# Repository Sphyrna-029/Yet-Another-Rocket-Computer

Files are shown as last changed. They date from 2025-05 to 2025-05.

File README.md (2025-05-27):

# Yet-Another-Rocket-Computer
YARC (Yet Another Rocket Comptuer). Rocket flight computers are all the craze nowa-days. This is my attempt at one.

##### Features
 - 3-axis gyroscope and a 3-axis accelerometer (MPU6050)
 - GPS (LC86G with built in patch)
 - Telemetry (1 Watt Ebyte E22 Lora Module)
 - Total footprint is 35mm x 90mm
<br/>
<br/>
Firmware will track flight events (launch, apogee, landing), altitude, location, and attitude. In addition to aiding in post flight recovery. 
<br/>
<br/>
<br/>

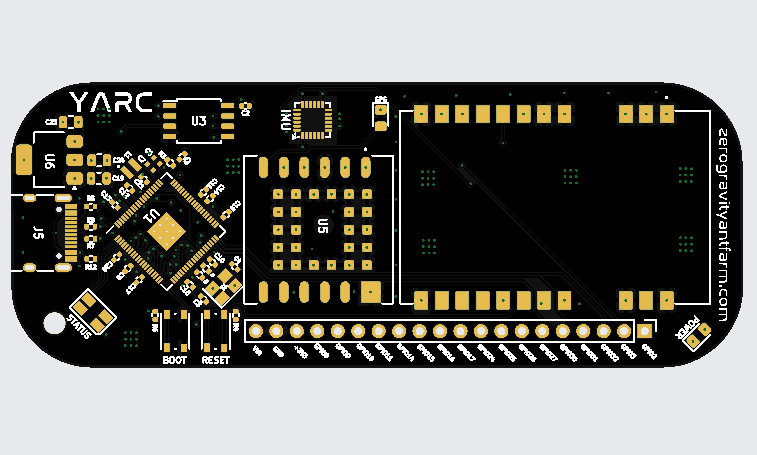
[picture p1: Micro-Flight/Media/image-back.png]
Board back.

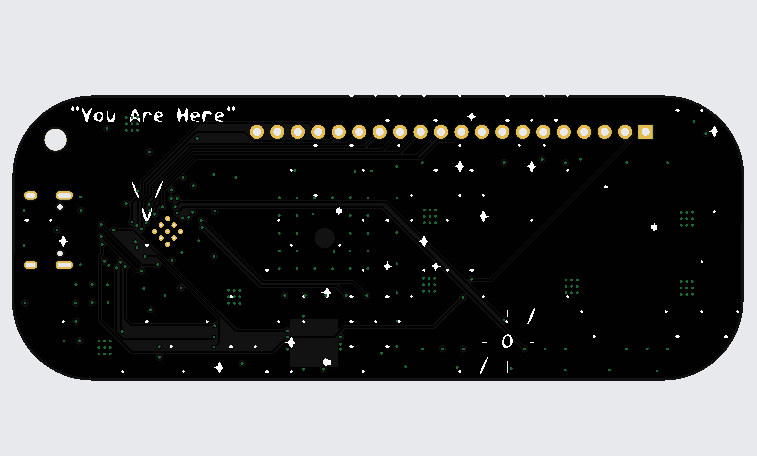
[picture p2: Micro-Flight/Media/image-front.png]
Board front.


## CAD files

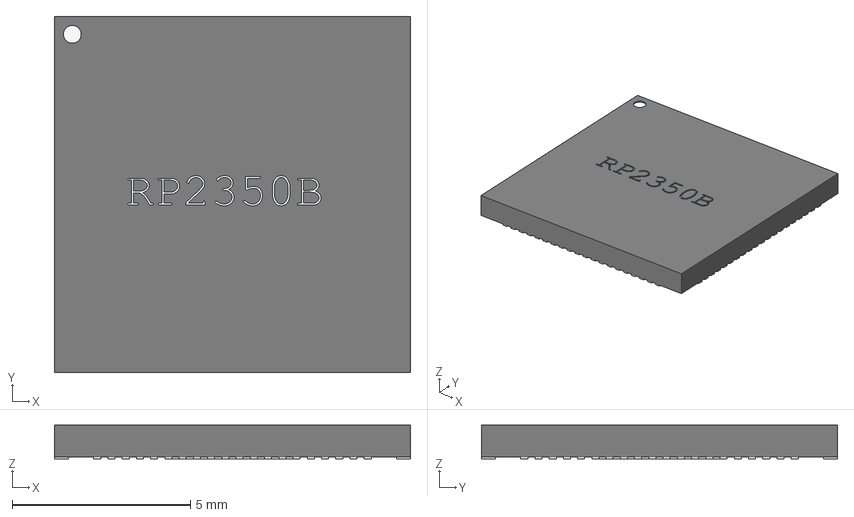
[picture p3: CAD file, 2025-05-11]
Micro-Flight/RP2350_QFN80.step
10.0 x 10.0 x 0.95 mm

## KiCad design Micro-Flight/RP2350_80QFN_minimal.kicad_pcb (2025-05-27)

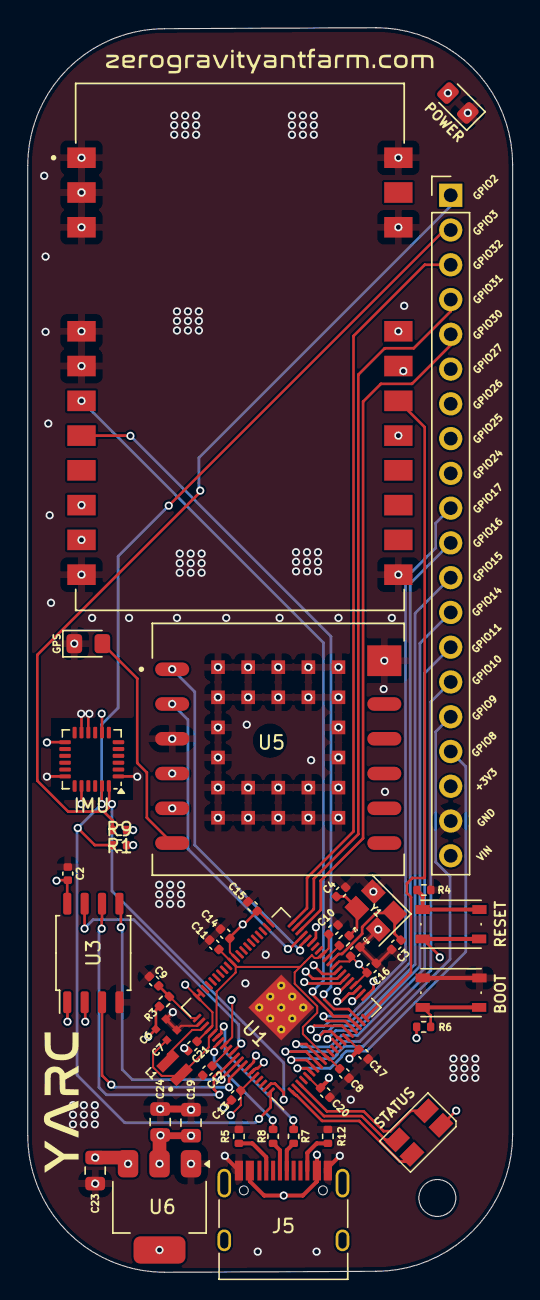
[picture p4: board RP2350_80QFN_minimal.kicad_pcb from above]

Board: 4 copper layers, 35.4 x 90.9 mm, 47 parts (0 on the bottom side), 53 nets.

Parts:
BOOT: SW_Push; SW_Push_1P1T_NO_Vertical_Wuerth_434133025816
C2, C8, C11, C12, C13, C14, C15, C16, C17, C18, C20, C21: 100n; C_0402_1005Metric
C3, C4: 15p; C_0402_1005Metric
C6, C7: 4.7u; C_0402_1005Metric_small_pads
C9, C10: 4.7u; C_0402_1005Metric
C19, C23, C24: 10u; C_0805_2012Metric
GPS: LED; LED_0805_2012Metric_Pad1.15x1.40mm_HandSolder
H3: MountingHole; MountingHole_2.7mm_M2.5
IMU: MPU-6050; InvenSense_QFN-24_4x4mm_P0.5mm
J2: Conn_01x20; PinHeader_1x20_P2.54mm_Vertical
J5: USB_C_Receptacle_USB2.0_14P; USB_C_Receptacle_HRO_TYPE-C-31-M-12
L1: 3.3u; L_pol_2016
POWER: LED; LED_0805_2012Metric_Pad1.15x1.40mm_HandSolder
R1, R9: 4.7k; R_0402_1005Metric
R2, R4, R6: 1k; R_0402_1005Metric
R3: 33; R_0402_1005Metric
R5, R12: 5.1k; R_0402_1005Metric
R7, R8: 27; R_0402_1005Metric
RESET: SW_Push; SW_Push_1P1T_NO_Vertical_Wuerth_434133025816
STATUS: LED_ARGB; LED_Avago_PLCC4_3.2x2.8mm_CW
U1: RP2350_80QFN; RP2350-QFN-80-1EP_10x10_P0.4mm_EP3.4x3.4mm_ThermalVias
U2: E22-900M30S; XCVR_E22-900M30S
U3: W25Q128JVS; SOIC-8_5.23x5.23mm_P1.27mm
U5: LC86G; XCVR_LC86G
U6: NCP1117-3.3_SOT223; SOT-223-3_TabPin2
Y1: ABM8-272-T3; Crystal_SMD_3225-4Pin_3.2x2.5mm

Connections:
+1V1: C7.1, C8.1, C10.1, C11.1, L1.1, U1.10 (DVDD), U1.32 (DVDD), U1.51 (DVDD), U1.65 (VREG_FB)
+3V3: C2.1, C6.1, C12.1, C13.1, C14.1, C15.1, C16.1, C17.1, C18.1, C19.1, C20.1, C21.1, C24.1, IMU.8 (VLOGIC), IMU.13 (VDD), J2.18, POWER.2 (A), R1.1, R3.1, R9.2, STATUS.1 (A), U1.5 (IOVDD), U1.15 (IOVDD), U1.24 (IOVDD), U1.29 (IOVDD), U1.41 (IOVDD), U1.50 (IOVDD), U1.59 (ADC_AVDD), U1.60 (IOVDD), U1.64 (VREG_VIN), U1.68 (USB_OTP_VDD), U1.69 (QSPI_IOVDD), U1.76 (IOVDD), U2.9 (VCC), U2.10 (VCC), U3.8 (VCC), U5.4 (VCC), U5.5 (V_BCKP), U6.2 (VO)
/FLASH_SS: R6.1, U1.75 (QSPI_SS), U3.1 (~CS)
/GPIO2: IMU.24 (SDA), J2.1, R1.2, U1.79 (GPIO2)
/GPIO3: IMU.23 (SCL), J2.2, R9.1, U1.80 (GPIO3)
/GPIO4: STATUS.2 (RK), U1.1 (GPIO4)
/GPIO5: STATUS.3 (GK), U1.2 (GPIO5)
/GPIO6: STATUS.4 (BK), U1.3 (GPIO6)
/GPIO8: J2.17, U1.6 (GPIO8)
/GPIO9: J2.16, U1.7 (GPIO9)
/GPIO10: J2.15, U1.8 (GPIO10)
/GPIO11: J2.14, U1.9 (GPIO11)
/GPIO14: J2.13, U1.13 (GPIO14)
/GPIO15: J2.12, U1.14 (GPIO15)
/GPIO16: J2.11, U1.16 (GPIO16)
/GPIO17: J2.10, U1.17 (GPIO17)
/GPIO18: U1.18 (GPIO18), U2.6 (RXEN)
/GPIO19: U1.19 (GPIO19), U2.7 (TXEN)
/GPIO20: U1.20 (GPIO20), U2.17 (MOSI)
/GPIO21: U1.21 (GPIO21), U2.19 (NSS)
/GPIO22: U1.22 (GPIO22), U2.18 (SCK)
/GPIO23: U1.23 (GPIO23), U2.16 (MISO)
/GPIO24: J2.9, U1.25 (GPIO24)
/GPIO25: J2.8, U1.26 (GPIO25)
/GPIO26: J2.7, U1.27 (GPIO26)
/GPIO27: J2.6, U1.28 (GPIO27)
/GPIO28: U1.36 (GPIO28), U5.1 (RXD)
/GPIO29: U1.37 (GPIO29), U5.2 (TXD)
/GPIO30: J2.5, U1.38 (GPIO30)
/GPIO31: J2.4, U1.39 (GPIO31)
/GPIO32: J2.3, U1.40 (GPIO32)
/QSPI_SCLK: U1.71 (QSPI_SCLK), U3.6 (CLK)
/QSPI_SD0: U1.72 (QSPI_SD0), U3.5 (DI(IO0))
/QSPI_SD1: U1.74 (QSPI_SD1), U3.2 (DO(IO1))
/QSPI_SD2: U1.73 (QSPI_SD2), U3.3 (IO2)
/QSPI_SD3: U1.70 (QSPI_SD3), U3.7 (IO3)
/RUN: RESET.2, U1.35 (RUN)
/USB_D+: J5.A6 (D+), R7.1
/USB_D-: J5.A7 (D-), R8.1
/VREG_AVDD: C9.1, R3.2, U1.61 (VREG_AVDD)
/VREG_LX: L1.2, U1.63 (VREG_LX)
/XIN: C3.1, U1.30 (XIN), Y1.1
/XOUT: R2.1, U1.31 (XOUT)
/~USB_BOOT: BOOT.2, R6.2
GND: BOOT.1, C2.2, C3.2, C4.2, C6.2, C7.2, C8.2, C9.2, C10.2, C11.2, C12.2, C13.2, C14.2, C15.2, C16.2, C17.2, C18.2, C19.2, C20.2, C21.2, C23.2, C24.2, GPS.1 (K), IMU.1 (CLKIN), IMU.10 (REGOUT), IMU.11 (FSYNC), IMU.18 (GND), IMU.20 (CPOUT), J2.19, J5.A1 (GND), J5.A12 (GND), J5.B1 (GND), J5.B12 (GND), POWER.1 (K), R4.2, R5.1, R12.1, U1.62 (VREG_PGND), U1.81 (GND), U2.1 (GND), U2.2 (GND), U2.3 (GND), U2.4 (GND), U2.5 (GND), U2.11 (GND), U2.12 (GND), U2.20 (GND), U2.22 (GND), U3.4 (GND), U5.3 (GND), U5.12 (GND), U5.13 (GND), U5.14 (GND), U5.15 (GND), U5.16 (GND), U5.17 (GND), U5.18 (GND), U5.19 (GND), U5.20 (GND), U5.21 (GND), U5.22 (GND), U5.23 (GND), U5.24 (GND), U5.25 (GND), U5.26 (GND), U5.27 (GND), U5.28 (GND), U5.29 (GND), U5.30 (GND), U5.31 (GND), U5.32 (GND), U5.33 (GND), U5.34 (GND), U5.35 (GND), U5.36 (GND), U6.1 (GND), Y1.2, Y1.4
unnamed: C4.1, R2.2, Y1.3
unnamed: GPS.2 (A), U5.6 (1PPS)
unnamed: J5.A5 (CC1), R5.2
unnamed: J5.B5 (CC2), R12.2
unnamed: R4.1, RESET.1
unnamed: R8.2, U1.66 (USB_DM)
unnamed: R7.2, U1.67 (USB_DP)
VBUS: C23.1, J2.20, J5.A4 (VBUS), J5.A9 (VBUS), J5.B4 (VBUS), J5.B9 (VBUS), U6.3 (VI)

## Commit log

2025-05-11 Rev A
    [RP2350_80QFN_minimal.kicad_pcb, RP2350_80QFN_minimal.kicad_sch, RP2350_80QFN_minimal.sch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]
2025-05-27 REV B
    [RP2350_80QFN_minimal.kicad_pcb]
